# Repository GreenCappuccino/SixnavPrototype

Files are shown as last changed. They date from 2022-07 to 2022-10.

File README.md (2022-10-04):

sixnav banner
# Shamrock Sixnav Prototype Board
This board is intended as a test platform for the development of an open-source knob
with 6 degrees of freedom (6DOF), based on the ideas expressed in expired US patent
[US20030102426A1](https://patents.google.com/patent/US20030102426A1).

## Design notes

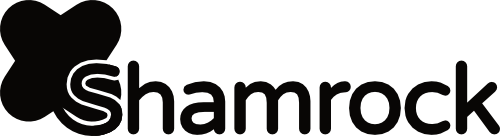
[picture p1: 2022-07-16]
src/ecad/shamrock mono.png

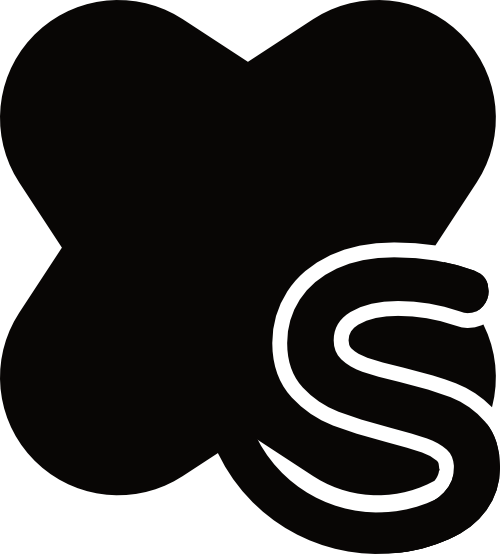
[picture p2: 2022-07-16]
src/ecad/shamrock-mono-square.png

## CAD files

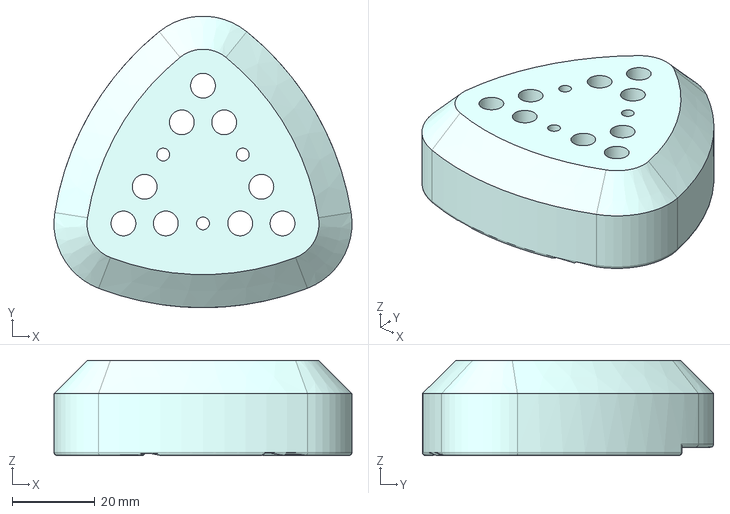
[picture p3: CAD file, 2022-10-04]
src/mcad/Knob - Cover.step
72.1 x 70.5 x 23.0 mm

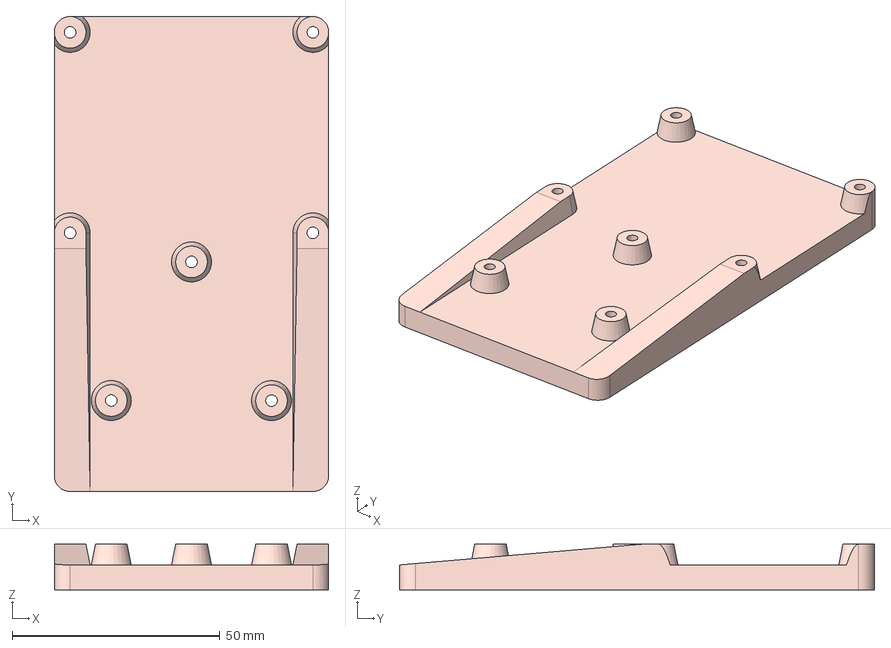
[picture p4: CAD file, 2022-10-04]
src/mcad/Base - Base.step
66.0 x 114.3 x 11.0 mm

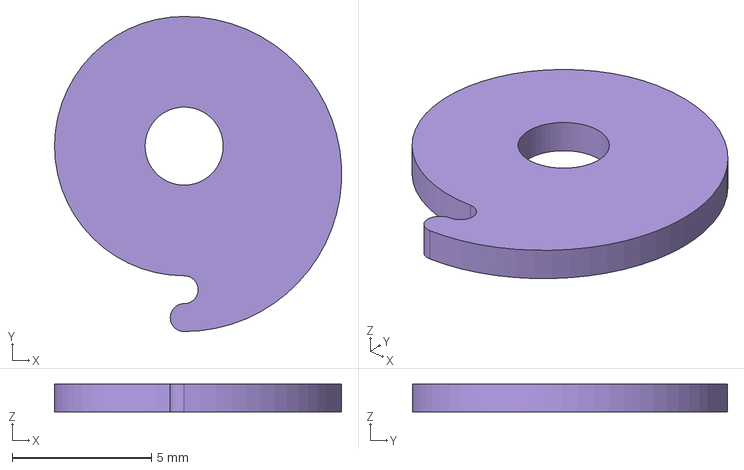
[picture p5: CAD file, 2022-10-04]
src/mcad/Knob - Spring Plate.step
10.3 x 11.3 x 1.00 mm

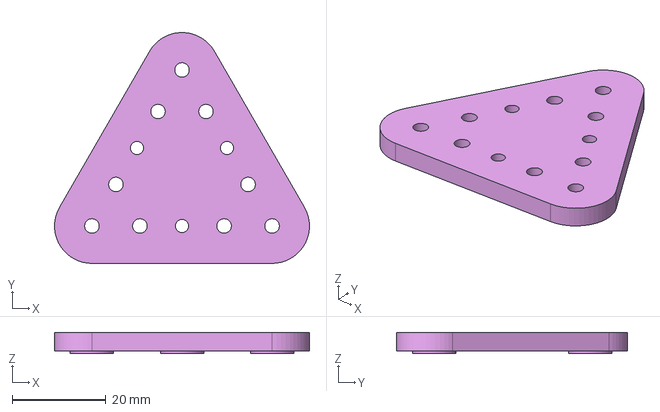
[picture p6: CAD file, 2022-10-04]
src/mcad/Knob - Frame.step
54.5 x 49.3 x 4.50 mm

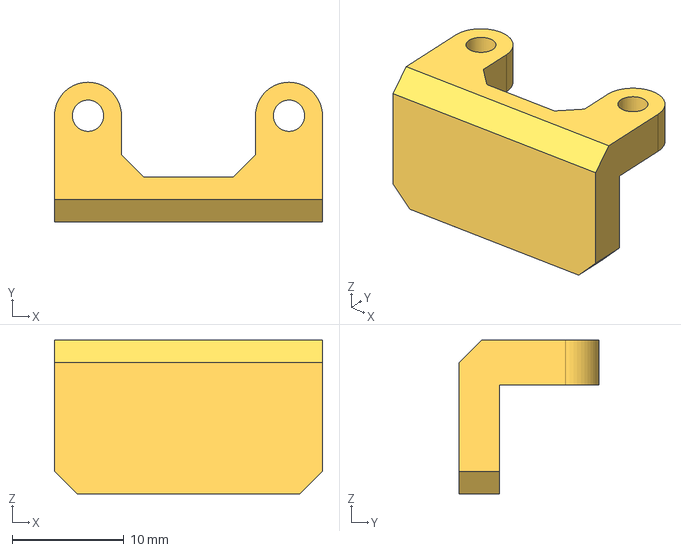
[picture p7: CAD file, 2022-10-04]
src/mcad/Knob - Opto.step
24.0 x 12.5 x 13.8 mm

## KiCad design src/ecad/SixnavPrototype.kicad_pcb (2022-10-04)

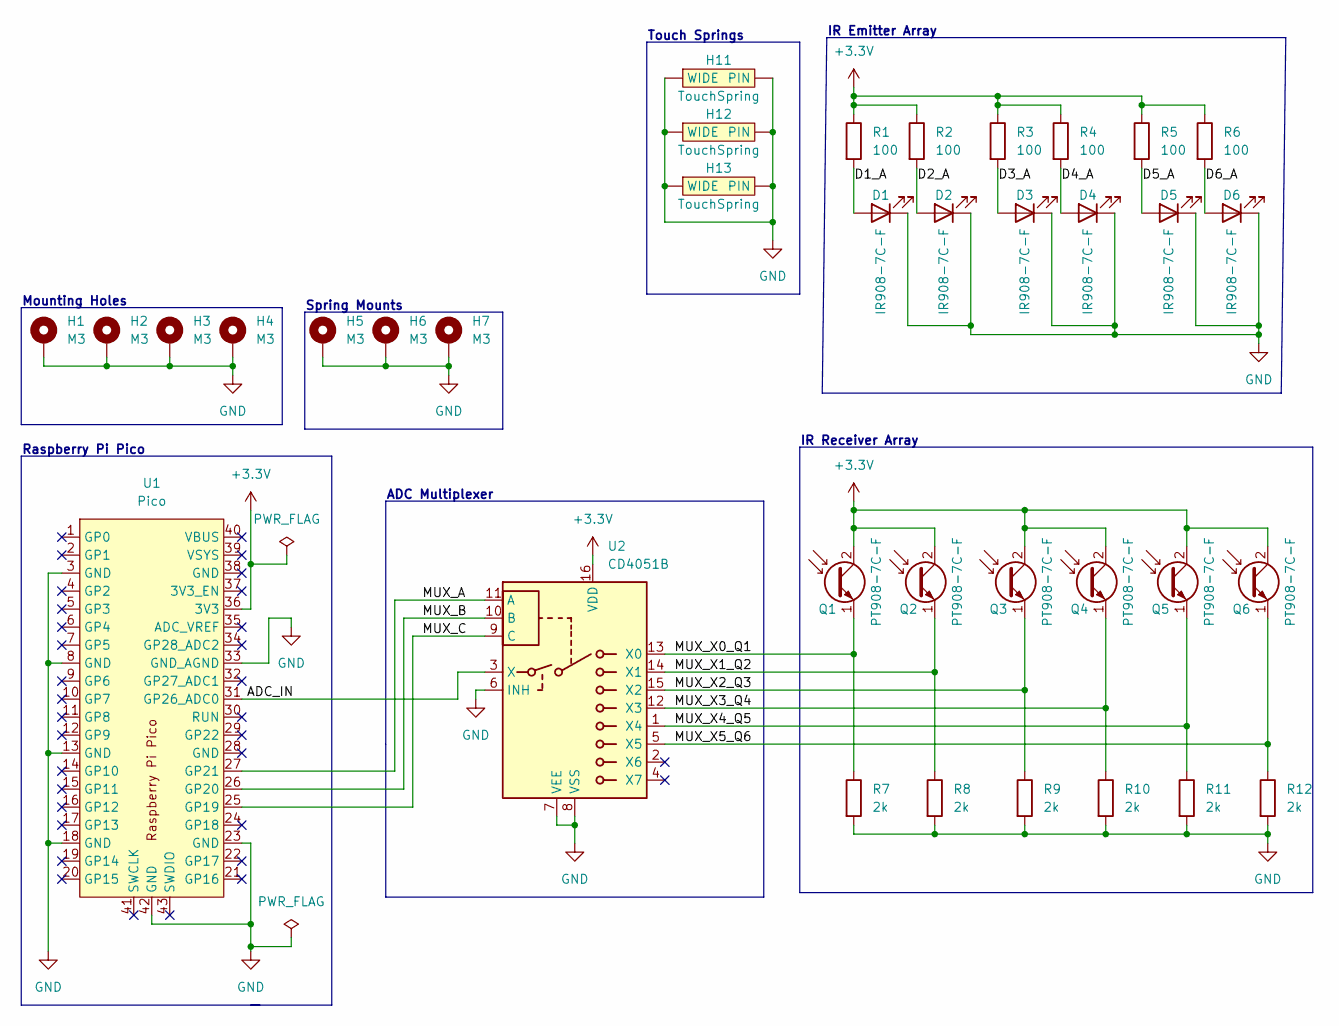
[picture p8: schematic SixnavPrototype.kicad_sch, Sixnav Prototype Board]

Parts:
D1, D2, D3, D4, D5, D6: IR908-7C-F
H1, H2, H3, H4, H5, H6, H7: M3; MountingHole_3.2mm_M3_DIN965_Pad
H11, H12, H13: TouchSpring; TouchSpring10mm
Q1, Q2, Q3, Q4, Q5, Q6: PT908-7C-F
R1, R2, R3, R4, R5, R6: 100; R_Axial_DIN0204_L3.6mm_D1.6mm_P5.08mm_Horizontal
R7, R8, R9, R10, R11, R12: 2k; R_Axial_DIN0204_L3.6mm_D1.6mm_P5.08mm_Horizontal
U1: Pico; Raspberry Pi Pico
U2: CD4051B; DIP-16_W7.62mm

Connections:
+3.3V: Q1.2 (C), Q2.2 (C), Q3.2 (C), Q4.2 (C), Q5.2 (C), Q6.2 (C), R1.1, R2.1, R3.1, R4.1, R5.1, R6.1, U1.36 (3V3), U2.16 (VDD)
/ADC_IN: U1.31 (GP26_ADC0), U2.3 (X)
/D1_A: D1.1 (A), R1.2
/D2_A: D2.1 (A), R2.2
/D3_A: D3.1 (A), R3.2
/D4_A: D4.1 (A), R4.2
/D5_A: D5.1 (A), R5.2
/D6_A: D6.1 (A), R6.2
/MUX_A: U1.27 (GP21), U2.11 (A)
/MUX_B: U1.26 (GP20), U2.10 (B)
/MUX_C: U1.25 (GP19), U2.9 (C)
/MUX_X0_Q1: Q1.1 (E), R7.1, U2.13 (X0)
/MUX_X1_Q2: Q2.1 (E), R8.1, U2.14 (X1)
/MUX_X2_Q3: Q3.1 (E), R9.1, U2.15 (X2)
/MUX_X3_Q4: Q4.1 (E), R10.1, U2.12 (X3)
/MUX_X4_Q5: Q5.1 (E), R11.1, U2.1 (X4)
/MUX_X5_Q6: Q6.1 (E), R12.1, U2.5 (X5)
GND: D1.2 (K), D2.2 (K), D3.2 (K), D4.2 (K), D5.2 (K), D6.2 (K), H1.1, H2.1, H3.1, H4.1, H5.1, H6.1, H7.1, H11.1 (WIDE), H11.2 (PIN), H12.1 (WIDE), H12.2 (PIN), H13.1 (WIDE), H13.2 (PIN), R7.2, R8.2, R9.2, R10.2, R11.2, R12.2, U1.3 (GND), U1.8 (GND), U1.13 (GND), U1.18 (GND), U1.23 (GND), U1.33 (GND_AGND), U1.42 (GND), U2.6 (INH), U2.7 (VEE), U2.8 (VSS)

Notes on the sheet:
Mounting Holes
ADC Multiplexer
IR Emitter Array
Touch Springs
Raspberry Pi Pico
Spring Mounts
IR Receiver Array

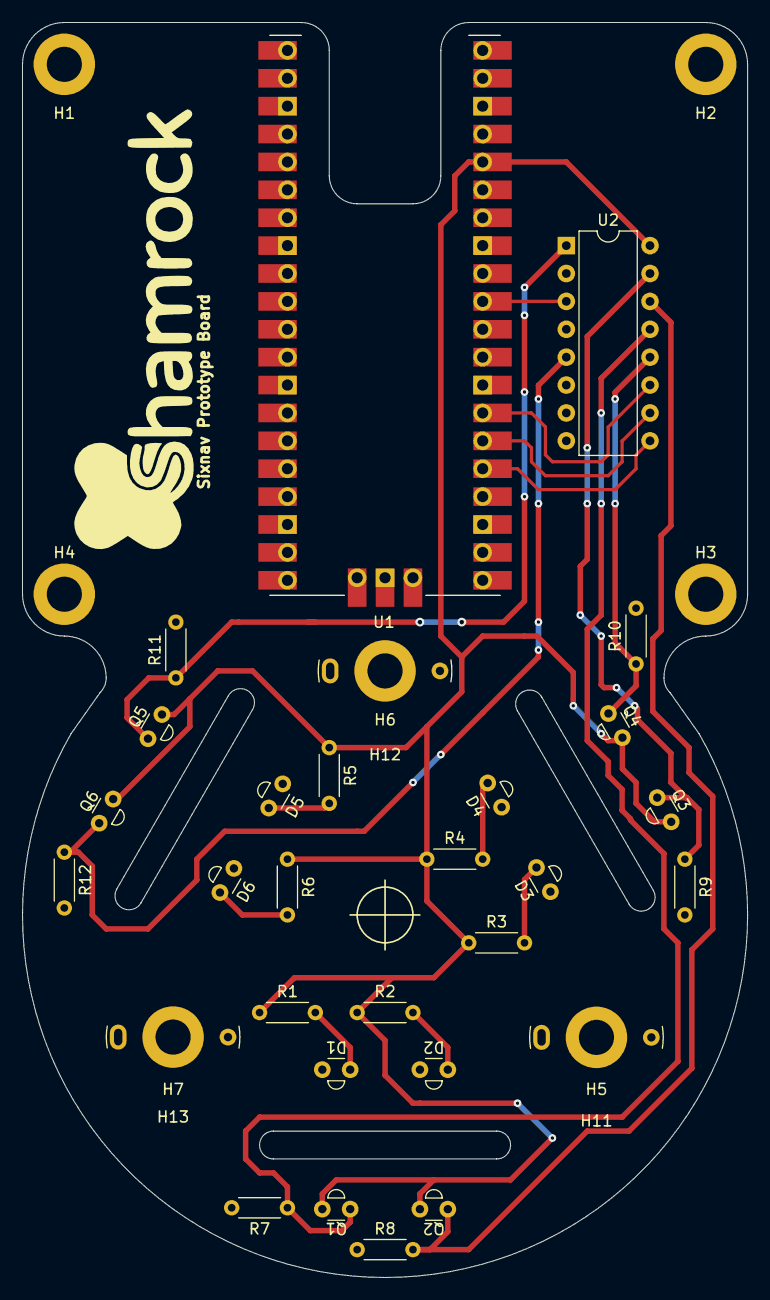
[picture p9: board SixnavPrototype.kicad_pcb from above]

Board: 2 copper layers, 66.0 x 114.3 mm, 36 parts (0 on the bottom side), 18 nets.

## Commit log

2022-07-16 Initial Draft
    [Sixnav.kicad_pcb, Sixnav.kicad_sch]
2022-07-16 Second Draft
    It was only until after I finished routing this that I realized that the
    PT908 and IR908 have flipped pin numbers. I'm going to have to aquire a
    separate foorprint for the PT908.
    [Sixnav.kicad_pcb, Sixnav.kicad_sch]
2022-07-16 PT908 footprint
    [Sixnav.kicad_pcb, Sixnav.kicad_sch]
2022-07-16 First JLCPCB order
    [Sixnav.kicad_pcb]
2022-07-22 Initial CI/CD
    [SixnavPrototype.kicad_pcb, SixnavPrototype.kicad_sch]
2022-07-25 Replaced symbols, footprints, models, with lib
    Internal libraries also fix the reversed phototransistor issue.
    [Sixnav.kicad_pcb, Sixnav.kicad_sch, SixnavPrototype.kicad_pcb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]
2022-07-31 fix pico castellations
2022-07-31 add symbols, fix LED polarity
    [SixnavPrototype.kicad_pcb, SixnavPrototype.kicad_sch]
2022-08-01 add mcad STEP
    [Base - Base.step, Knob - Cover.step, Knob - Frame.step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]
2022-10-04 Revision 0.2.0 ECAD
    [SixnavPrototype.kicad_pcb, SixnavPrototype.kicad_sch]
2022-10-04 Revision 0.2.0 MCAD
    [Base - Base.step, Knob - Cover.step, Knob - Frame.step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]
